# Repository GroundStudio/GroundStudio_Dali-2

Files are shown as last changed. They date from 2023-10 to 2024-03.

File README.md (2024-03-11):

GroundStudio Dali-2
====================================
Dali-2 Module REV1 0 0

Get it from [ardushop.ro](https://ardushop.ro/ro/home/2657-groundstudio-dali-2.html)

Explore all the GroundStudio products at [GroundStudio.ro](https://groundstudio.ro/)

Description
-------------------
This module can be used to convert the logic signal of a microcontroller from 5V to DALI bus level (9.5 V - 22.5 V) and control lighting systems compatible with the DALI-2 communication protocol.

It can be used together with a development board to control smart lighting systems that use the Dali-2 standard.

Contents
-------------------

* [/Documentation](https://github.com/GroundStudio/GroundStudio_Dali-2/tree/main/Documentation) -- Contains documentation written during creation of this repository, with readme.md index of its own!
* [/Hardware](https://github.com/GroundStudio/GroundStudio_Dali-2/tree/main/Hardware) -- Schematics, layout.

Versions
-------------------
*(Not all tags shown)*
* [V0.0.1] Initial version

License
-------------------

This is released under the [Attribution-ShareAlike 4.0 International (CC BY-SA 4.0)](https://creativecommons.org/licenses/by-sa/4.0/) license. 
**You are welcome to use this for commercial purposes.**

Please consider contributing back to this project or others to help the open-source hardware community continue to thrive and grow! 

Certifications:

[Open Source Hardware Association](https://certification.oshwa.org/ro000022.html)   
   
certification-mark-RO000022-wide (https://certification.oshwa.org/ro000022.html)

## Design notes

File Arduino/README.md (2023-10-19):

2023-03-30proiectDali-2_bb

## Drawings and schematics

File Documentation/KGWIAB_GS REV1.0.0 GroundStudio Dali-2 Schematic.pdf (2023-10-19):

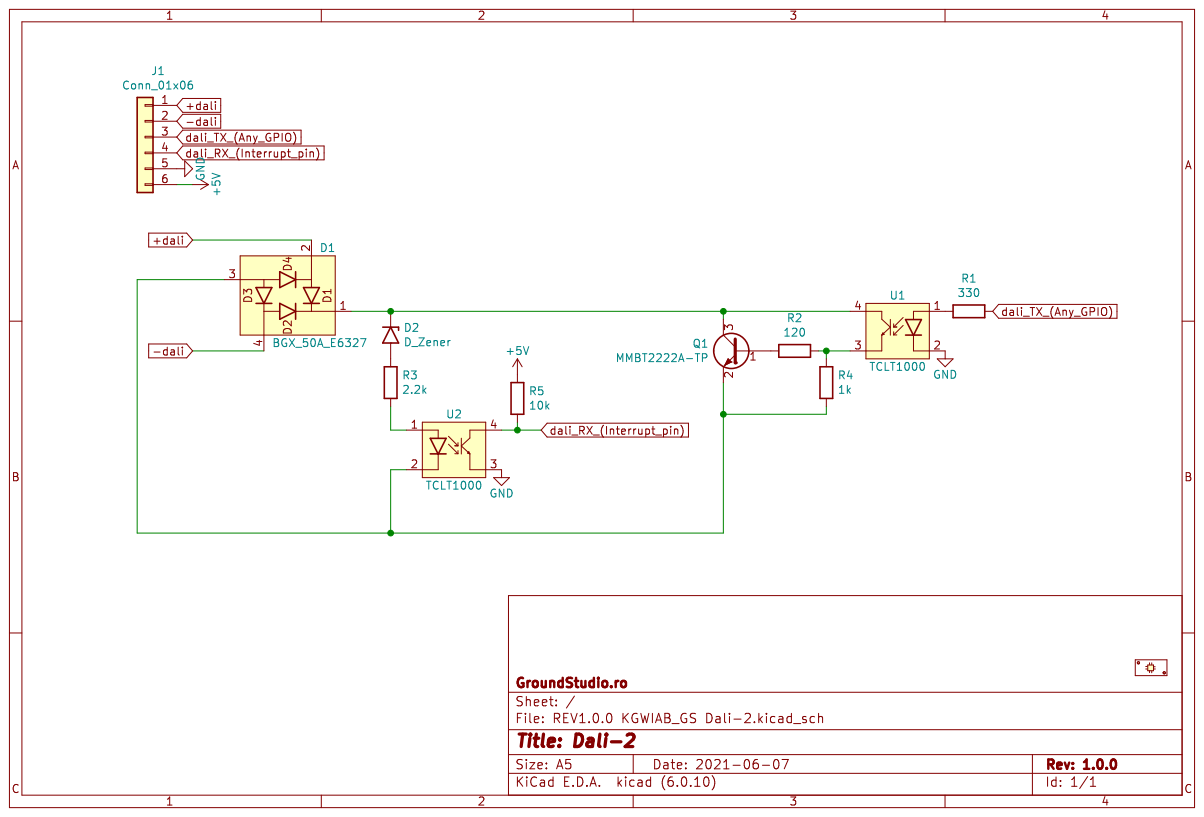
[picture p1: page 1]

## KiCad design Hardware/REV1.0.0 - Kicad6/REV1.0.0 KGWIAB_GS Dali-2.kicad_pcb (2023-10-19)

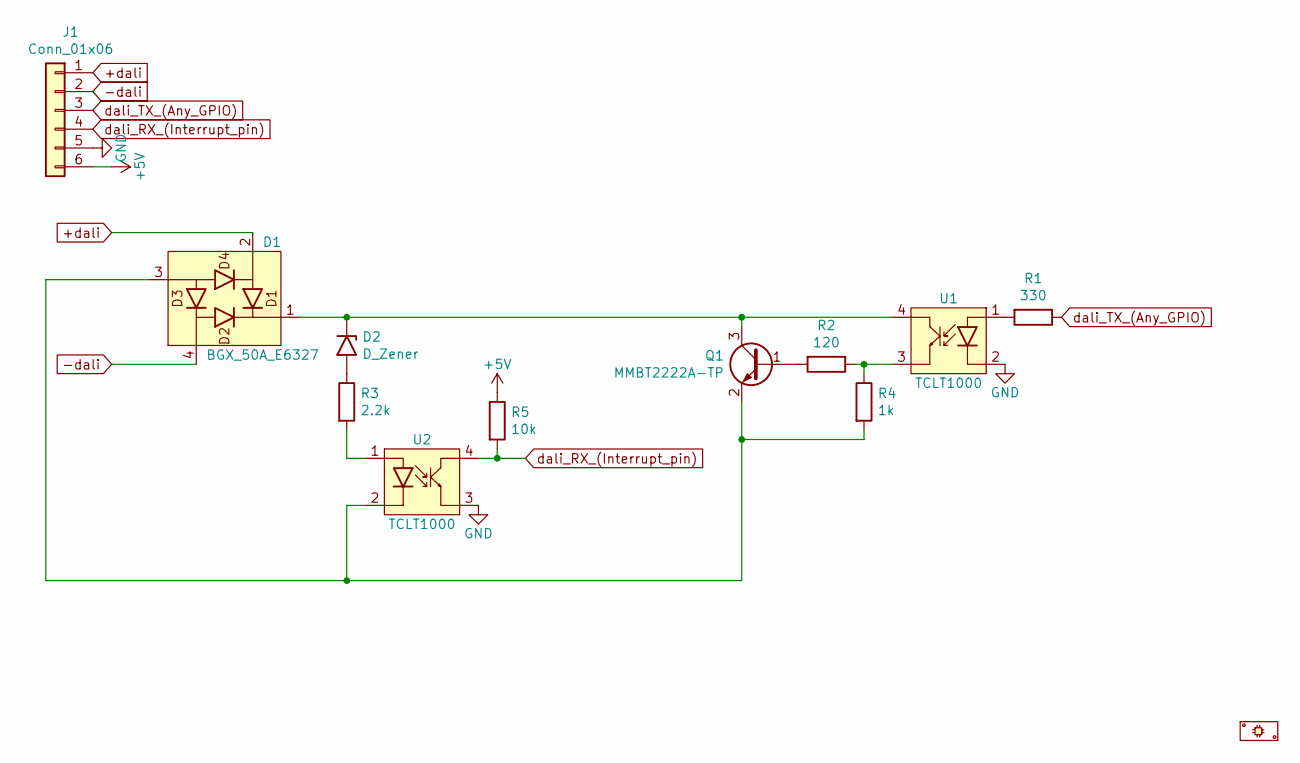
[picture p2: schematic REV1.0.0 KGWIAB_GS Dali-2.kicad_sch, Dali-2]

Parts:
D1: BGX_50A_E6327; SOT-143; MPN BGX 50A E6327; LCSC C534261
D2: D_Zener; SOD-523; MPN MM5Z5V1; LCSC C2832572
J1: Conn_01x06; PinHeader_1x06_P2.54mm_Vertical_Male; MPN C37208; LCSC C37208
P1: PCB; MPN KGWIAB_GS_PCB
Q1: MMBT2222A-TP; SOT-23-3; MPN MMBT2222A-TP; LCSC C194252
R1: 330; R_0402_alt; MPN 0402WGF3300TCE; LCSC C25104
R2: 120; R_0402_alt; MPN RC-02W1200FT; LCSC C310190
R3: 2.2k; R_0402_alt; MPN RC-02W2201FT; LCSC C258093
R4: 1k; R_0402_alt; MPN RC-02W1001FT; LCSC C226166
R5: 10k; R_0402_alt; MPN 0402WGJ0103TCE; LCSC C25531
U1, U2: TCLT1000; SOP-4_P2.54_300mil; MPN TCLT1000; LCSC C110644

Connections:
+5V: J1.6, R5.1
+dali: D1.2, J1.1
-dali: D1.4, J1.2
GND: J1.5, U1.2 (K), U2.3 (E)
unnamed: D1.1, D2.1 (K), Q1.3 (C), U1.4 (C)
unnamed: D1.3, Q1.2 (E), R4.2, U2.2 (K)
unnamed: D2.2 (A), R3.1
unnamed: Q1.1 (B), R2.2
unnamed: R1.2, U1.1 (A)
unnamed: R2.1, R4.1, U1.3 (E)
unnamed: R3.2, U2.1 (A)
dali_RX_(Interrupt_pin): J1.4, R5.2, U2.4 (C)
dali_TX_(Any_GPIO): J1.3, R1.1

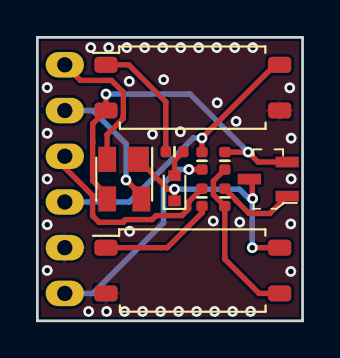
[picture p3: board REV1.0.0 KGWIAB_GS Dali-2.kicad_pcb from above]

Board: 2 copper layers, 14.7 x 15.7 mm, 11 parts (0 on the bottom side), 13 nets.

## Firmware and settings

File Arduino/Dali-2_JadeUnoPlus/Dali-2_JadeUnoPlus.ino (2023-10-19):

const int DALI_TX_PIN = 2;
const int DALI_RX_PIN = 3;
const int DALI_BIT_DELAY = 416;
long daliTimeout = 20000; //us, DALI response timeout

#define BROADCAST_C 0b11111111
#define ON_C 0b00000101
#define OFF_C 0b00000000

void setup() {
  Serial.begin(115200);
  help(); //Show help
  setupDali();
}

void help() {
  Serial.println("Enter one of the following commands in serial monitor:");
  Serial.println("help -  command list");
  Serial.println("on - broadcast on 100%");
  Serial.println("off -  broadcast off 0%");
  Serial.println();
}

////////////DALI

void setupDali(){
  pinMode(DALI_TX_PIN, OUTPUT);
  digitalWrite(DALI_TX_PIN, LOW); 
}

void startDali(){
    digitalWrite(DALI_TX_PIN, LOW);
}

void startBit(){
  sendBit(1);
}

void stopBits() {
  digitalWrite(DALI_TX_PIN, LOW);
  delayMicroseconds(4 * DALI_BIT_DELAY);
}

void sendBit(int pBit) {
  if(pBit) //send 1
  {
    digitalWrite(DALI_TX_PIN, HIGH);
    delayMicroseconds(DALI_BIT_DELAY);
    digitalWrite(DALI_TX_PIN, LOW);
    delayMicroseconds(DALI_BIT_DELAY);
    }
  else{
    digitalWrite(DALI_TX_PIN, LOW);
    delayMicroseconds(DALI_BIT_DELAY);
    digitalWrite(DALI_TX_PIN, HIGH);
    delayMicroseconds(DALI_BIT_DELAY);
  }
}

void sendByte(uint8_t b) {
  for (int i = 7; i >= 0; i--) 
  {
    sendBit((b >> i) & 1);
  }
}

void transmit(uint8_t cmd1, uint8_t cmd2) { // transmit commands to DALI bus (address byte, command byte)
  startBit();
  sendByte(cmd1);
  sendByte(cmd2);
  stopBits();
}

void loop() {
  int i;
  int cmd1;
  int cmd2;
  String comMsg;

  // Read command from port
  delay(1000);

  while (Serial.available()) {
    comMsg = comMsg + (char)(Serial.read());
  }; // read data from serial

  if (comMsg == "on") {
   transmit(BROADCAST_C, ON_C);
  }; // broadcast, 100%

  if (comMsg == "off") {
    transmit(BROADCAST_C, OFF_C);
  }; // broadcast, 0%

  if (comMsg == "help") {
    help();
  }; //help
  
}
